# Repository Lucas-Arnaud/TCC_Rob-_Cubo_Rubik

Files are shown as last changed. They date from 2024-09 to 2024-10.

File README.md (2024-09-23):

# Robô Solucionador do Cubo de Rubik com uso de motores de passo e sensores de cor
Trabalho de Conclusão de Curso desenvolvido por Lucas Arnaud de Araújo e orientação do professor Dr. José Rodrigues de Oliveira Neto  submetido ao Departamento de Engenharia Mecânica da Universidade Federal de Pernambuco como requisito parcial para obtenção do título de Bacharel em Engenharia Mecânica.
## Resumo
Este projeto apresenta o desenvolvimento de um robô solucionador do cubo de Rubik, focando em velocidade de resolução e simplicidade da leitura das cores do cubo. Sendo assim, o robô foi projetado com o objetivo de identificar as cores das peças do cubo usando sensores de cor e, com base nesses dados, aplicar um algoritmo eficiente para calcular e executar a sequência de movimentos necessária, com uso de motores de passo, para solucionar o quebra-cabeça. Para esse fim, foram abordados aspectos específicos de projeto mecânico, eletrônica, programação e algoritmos. Com isso, o robô desenvolvido utiliza de seis motores de passo conectados aos eixos centrais do cubo, permitindo a rotação ordenada das faces, para realização da leitura e da resolução do cubo. 

Por outro lado, a leitura das cores é realizada com dois sensores de cor, a partir de um método próprio que realiza a leitura dos 48 quadrados com 60 movimentos das faces. Além disso, se implementou o algoritmo k-ésimo vizinho mais próximo (KNN, do inglês K-nearest neighbors) para classificar em cores os valores capturados pelos sensores e também um código para calcular a precisão das leituras automaticamente a partir de um embaralhamento aleatório empregado no robô. Ademais, utilizou-se uma implementação em código do algoritmo de Kociemba para encontrar a solução do cubo com no máximo 20 movimentos. Além da construção do robô, foram explorados conceitos importantes no uso de microcontroladores e de transferências de dados para integrar sensores e motores com um computador e viabilizar a leitura e a resolução do cubo. 

O projeto foi validado em testes para diferentes padrões do cubo e demonstrou sua capacidade de operar de forma eficaz. Nessas avaliações, o robô alcançou uma mediana de 39 leituras corretas e acertou 1375 das 1776 leituras (77,42\%) de cores. Acerca da velocidade, foi alcançado um tempo mínimo de resolução de 3,3 segundos, um desempenho comparável a projetos de referência na área.
## Imagens

## Importante
Para compreensão detalhada do projeto mecânico, montagem do hardware, códigos implementados, funcionamento do projeto e suas referências consultar o PDF nomeado **TCC_Lucas_Arnaud**.

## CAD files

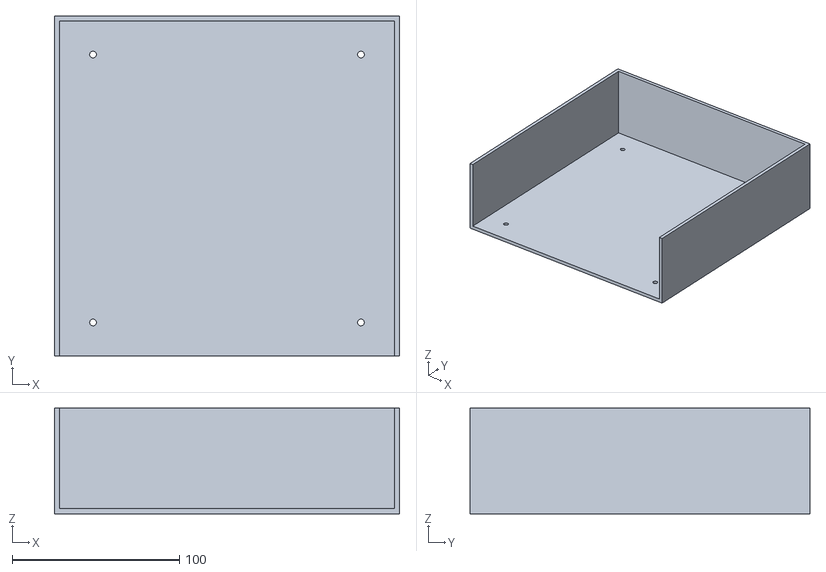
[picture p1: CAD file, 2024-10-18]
PEÇAS_STL/Caixa_Inferior.stl
206.0 x 203.0 x 63.0

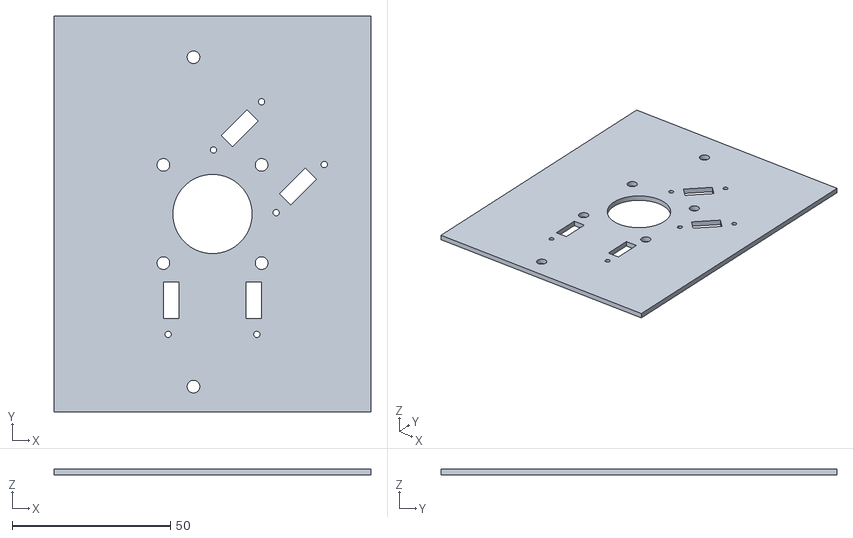
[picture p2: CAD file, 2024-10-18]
PEÇAS_STL/Base_Superior.stl
100.0 x 125.0 x 2.00

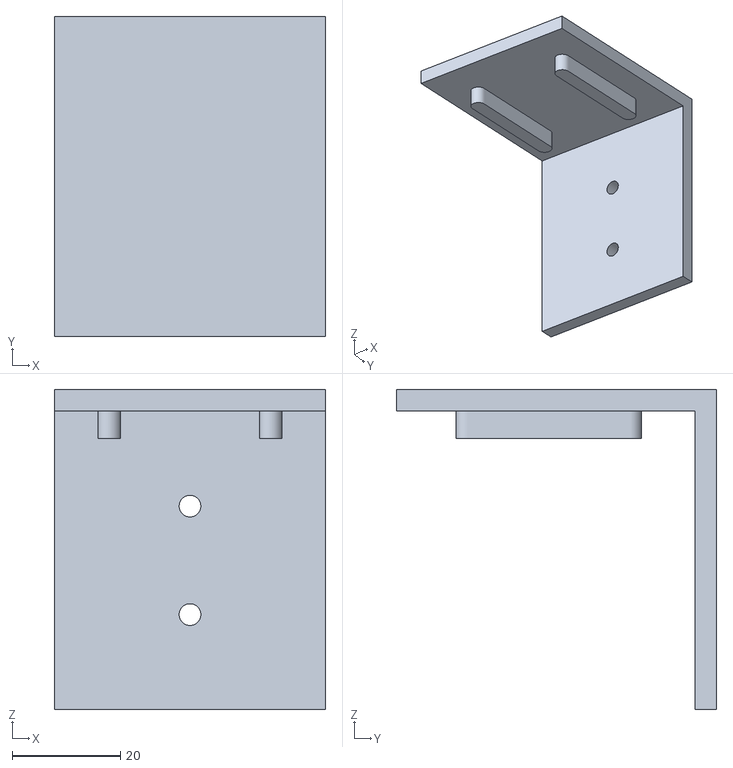
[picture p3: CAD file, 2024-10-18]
PEÇAS_STL/Suporte_Apoio_Reorientado.stl
50.0 x 59.0 x 59.0

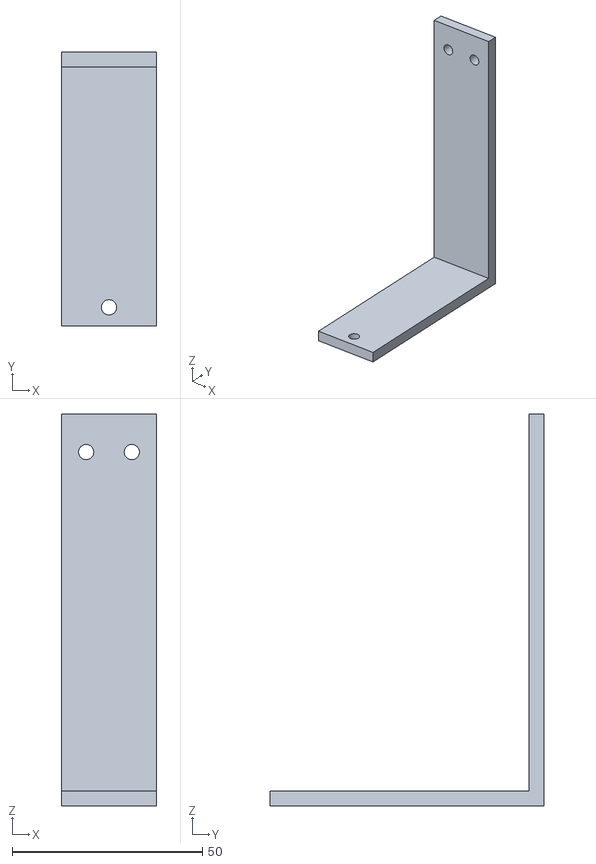
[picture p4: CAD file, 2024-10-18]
PEÇAS_STL/Suporte_em_L.stl
25.0 x 72.0 x 103.0

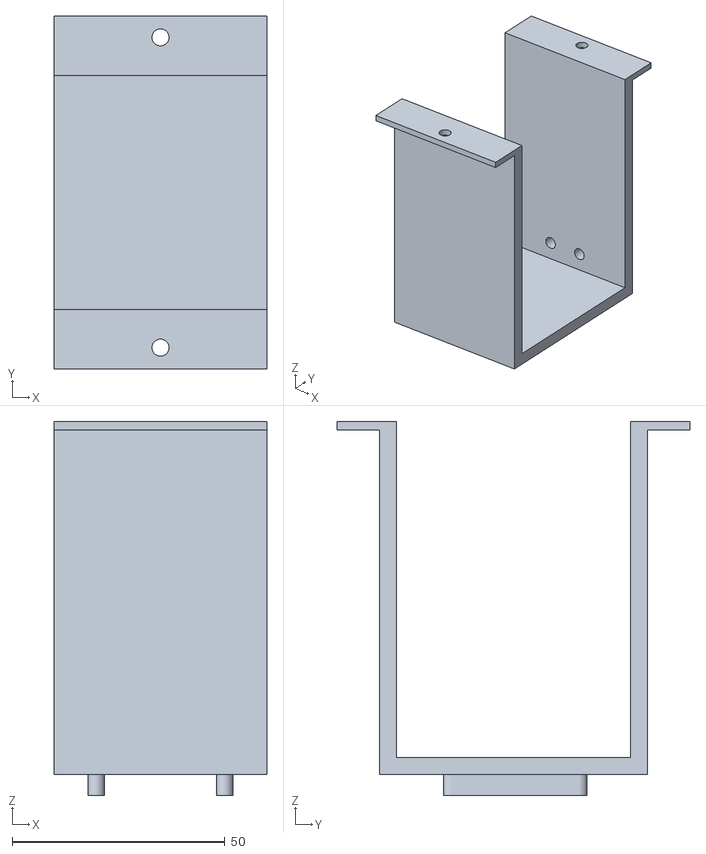
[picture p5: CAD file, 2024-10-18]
PEÇAS_STL/Suportes_Apoio.stl
50.0 x 83.0 x 88.0

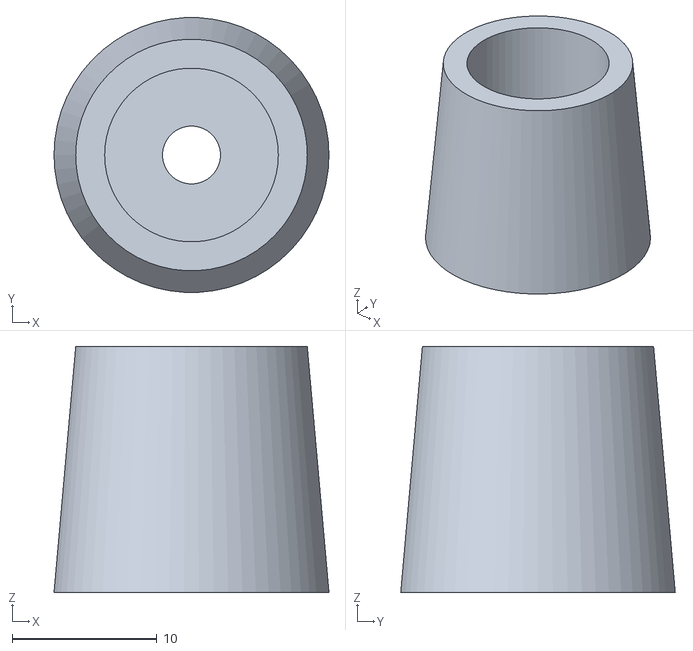
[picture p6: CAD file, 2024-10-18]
PEÇAS_STL/Pezinho (1).stl
19.0 x 19.0 x 17.0

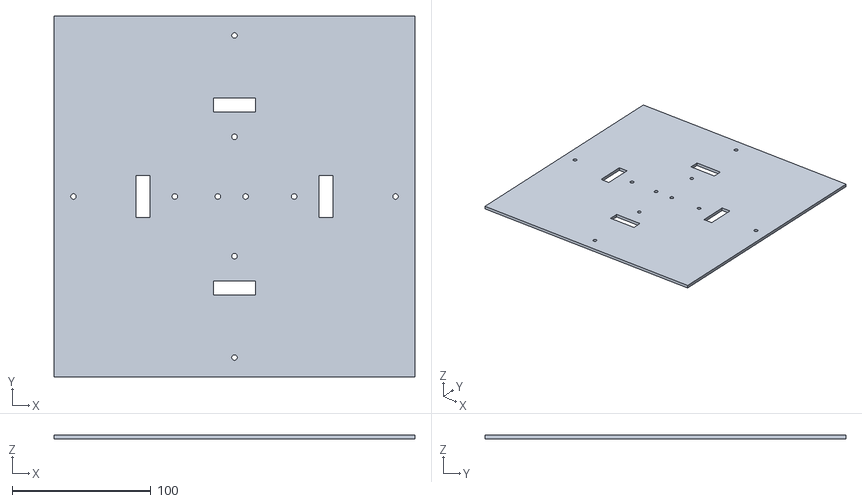
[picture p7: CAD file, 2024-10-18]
PEÇAS_STL/Base_Sustentação_Geral.stl
260.0 x 260.0 x 3.00

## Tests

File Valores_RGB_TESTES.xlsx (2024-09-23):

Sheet: Valores_RGB_Testes
TESTE | SENSOR | PADRÃO | TESTE | R | G | B | COR | SEQUÊNCIA LIDA | SEQUÊNCIA CORRETA
1 | SENSOR 1 | PADRÃO 1 | TESTE 1 | 117 | 115 | 120 | VERMELHO | BDBLBUBUFBUBUFRLRDRLDRFBRFLBRDDRFUBUFDUFUBLLRFUD | FDBLBUBUFBUBUFRLRDRLDRFBLFLBRDDRFUBULDRFUDLLRFUD
2 | SENSOR 1 | PADRÃO 1 | TESTE 1 | 116 | 63 | 53 | VERMELHO | BDBLBUBUFBUBUFRLRDRLDRFBRFLBRDDRFUBUFDUFUBLLRFUD | FDBLBUBUFBUBUFRLRDRLDRFBLFLBRDDRFUBULDRFUDLLRFUD
3 | SENSOR 1 | PADRÃO 1 | TESTE 1 | 152 | 58 | 60 | VERMELHO | BDBLBUBUFBUBUFRLRDRLDRFBRFLBRDDRFUBUFDUFUBLLRFUD | FDBLBUBUFBUBUFRLRDRLDRFBLFLBRDDRFUBULDRFUDLLRFUD
4 | SENSOR 1 | PADRÃO 1 | TESTE 1 | 146 | 58 | 60 | VERMELHO | BDBLBUBUFBUBUFRLRDRLDRFBRFLBRDDRFUBUFDUFUBLLRFUD | FDBLBUBUFBUBUFRLRDRLDRFBLFLBRDDRFUBULDRFUDLLRFUD
5 | SENSOR 1 | PADRÃO 1 | TESTE 1 | 183 | 89 | 60 | LARANJA | BDBLBUBUFBUBUFRLRDRLDRFBRFLBRDDRFUBUFDUFUBLLRFUD | FDBLBUBUFBUBUFRLRDRLDRFBLFLBRDDRFUBULDRFUDLLRFUD
6 | SENSOR 1 | PADRÃO 1 | TESTE 1 | 170 | 84 | 60 | LARANJA | BDBLBUBUFBUBUFRLRDRLDRFBRFLBRDDRFUBUFDUFUBLLRFUD | FDBLBUBUFBUBUFRLRDRLDRFBLFLBRDDRFUBULDRFUDLLRFUD
7 | SENSOR 1 | PADRÃO 1 | TESTE 1 | 152 | 79 | 75 | LARANJA | BDBLBUBUFBUBUFRLRDRLDRFBRFLBRDDRFUBUFDUFUBLLRFUD | FDBLBUBUFBUBUFRLRDRLDRFBLFLBRDDRFUBULDRFUDLLRFUD
8 | SENSOR 1 | PADRÃO 1 | TESTE 1 | 177 | 94 | 60 | LARANJA | BDBLBUBUFBUBUFRLRDRLDRFBRFLBRDDRFUBUFDUFUBLLRFUD | FDBLBUBUFBUBUFRLRDRLDRFBLFLBRDDRFUBULDRFUDLLRFUD
9 | SENSOR 1 | PADRÃO 1 | TESTE 1 | 219 | 209 | 218 | BRANCO | BDBLBUBUFBUBUFRLRDRLDRFBRFLBRDDRFUBUFDUFUBLLRFUD | FDBLBUBUFBUBUFRLRDRLDRFBLFLBRDDRFUBULDRFUDLLRFUD
10 | SENSOR 1 | PADRÃO 1 | TESTE 1 | 225 | 209 | 218 | BRANCO | BDBLBUBUFBUBUFRLRDRLDRFBRFLBRDDRFUBUFDUFUBLLRFUD | FDBLBUBUFBUBUFRLRDRLDRFBLFLBRDDRFUBULDRFUDLLRFUD
11 | SENSOR 1 | PADRÃO 1 | TESTE 1 | 219 | 203 | 218 | BRANCO | BDBLBUBUFBUBUFRLRDRLDRFBRFLBRDDRFUBUFDUFUBLLRFUD | FDBLBUBUFBUBUFRLRDRLDRFBLFLBRDDRFUBULDRFUDLLRFUD
12 | SENSOR 1 | PADRÃO 1 | TESTE 1 | 219 | 203 | 218 | BRANCO | BDBLBUBUFBUBUFRLRDRLDRFBRFLBRDDRFUBUFDUFUBLLRFUD | FDBLBUBUFBUBUFRLRDRLDRFBLFLBRDDRFUBULDRFUDLLRFUD
13 | SENSOR 1 | PADRÃO 1 | TESTE 1 | 170 | 146 | 83 | AMARELO | BDBLBUBUFBUBUFRLRDRLDRFBRFLBRDDRFUBUFDUFUBLLRFUD | FDBLBUBUFBUBUFRLRDRLDRFBLFLBRDDRFUBULDRFUDLLRFUD
14 | SENSOR 1 | PADRÃO 1 | TESTE 1 | 170 | 141 | 83 | AMARELO | BDBLBUBUFBUBUFRLRDRLDRFBRFLBRDDRFUBUFDUFUBLLRFUD | FDBLBUBUFBUBUFRLRDRLDRFBLFLBRDDRFUBULDRFUDLLRFUD
15 | SENSOR 1 | PADRÃO 1 | TESTE 1 | 140 | 136 | 83 | AMARELO | BDBLBUBUFBUBUFRLRDRLDRFBRFLBRDDRFUBUFDUFUBLLRFUD | FDBLBUBUFBUBUFRLRDRLDRFBLFLBRDDRFUBULDRFUDLLRFUD
16 | SENSOR 1 | PADRÃO 1 | TESTE 1 | 152 | 146 | 98 | AMARELO | BDBLBUBUFBUBUFRLRDRLDRFBRFLBRDDRFUBUFDUFUBLLRFUD | FDBLBUBUFBUBUFRLRDRLDRFBLFLBRDDRFUBULDRFUDLLRFUD
17 | SENSOR 1 | PADRÃO 1 | TESTE 1 | 92 | 89 | 60 | VERDE | BDBLBUBUFBUBUFRLRDRLDRFBRFLBRDDRFUBUFDUFUBLLRFUD | FDBLBUBUFBUBUFRLRDRLDRFBLFLBRDDRFUBULDRFUDLLRFUD
18 | SENSOR 1 | PADRÃO 1 | TESTE 1 | 61 | 110 | 75 | VERDE | BDBLBUBUFBUBUFRLRDRLDRFBRFLBRDDRFUBUFDUFUBLLRFUD | FDBLBUBUFBUBUFRLRDRLDRFBLFLBRDDRFUBULDRFUDLLRFUD
19 | SENSOR 1 | PADRÃO 1 | TESTE 1 | 19 | 99 | 90 | VERDE | BDBLBUBUFBUBUFRLRDRLDRFBRFLBRDDRFUBUFDUFUBLLRFUD | FDBLBUBUFBUBUFRLRDRLDRFBLFLBRDDRFUBULDRFUDLLRFUD
20 | SENSOR 1 | PADRÃO 1 | TESTE 1 | 146 | 157 | 188 | VERDE | BDBLBUBUFBUBUFRLRDRLDRFBRFLBRDDRFUBUFDUFUBLLRFUD | FDBLBUBUFBUBUFRLRDRLDRFBLFLBRDDRFUBULDRFUDLLRFUD
21 | SENSOR 1 | PADRÃO 1 | TESTE 1 | 104 | 79 | 98 | AZUL | BDBLBUBUFBUBUFRLRDRLDRFBRFLBRDDRFUBUFDUFUBLLRFUD | FDBLBUBUFBUBUFRLRDRLDRFBLFLBRDDRFUBULDRFUDLLRFUD
22 | SENSOR 1 | PADRÃO 1 | TESTE 1 | 37 | 63 | 113 | AZUL | BDBLBUBUFBUBUFRLRDRLDRFBRFLBRDDRFUBUFDUFUBLLRFUD | FDBLBUBUFBUBUFRLRDRLDRFBLFLBRDDRFUBULDRFUDLLRFUD
23 | SENSOR 1 | PADRÃO 1 | TESTE 1 | 55 | 73 | 98 | AZUL | BDBLBUBUFBUBUFRLRDRLDRFBRFLBRDDRFUBUFDUFUBLLRFUD | FDBLBUBUFBUBUFRLRDRLDRFBLFLBRDDRFUBULDRFUDLLRFUD
24 | SENSOR 1 | PADRÃO 1 | TESTE 1 | 146 | 157 | 188 | AZUL | BDBLBUBUFBUBUFRLRDRLDRFBRFLBRDDRFUBUFDUFUBLLRFUD | FDBLBUBUFBUBUFRLRDRLDRFBLFLBRDDRFUBULDRFUDLLRFUD
25 | SENSOR 2 | PADRÃO 1 | TESTE 1 | 158 | 153 | 55 | VERMELHO | BDBLBUBUFBUBUFRLRDRLDRFBRFLBRDDRFUBUFDUFUBLLRFUD | FDBLBUBUFBUBUFRLRDRLDRFBLFLBRDDRFUBULDRFUDLLRFUD
26 | SENSOR 2 | PADRÃO 1 | TESTE 1 | 163 | 53 | 51 | VERMELHO | BDBLBUBUFBUBUFRLRDRLDRFBRFLBRDDRFUBUFDUFUBLLRFUD | FDBLBUBUFBUBUFRLRDRLDRFBLFLBRDDRFUBULDRFUDLLRFUD
27 | SENSOR 2 | PADRÃO 1 | TESTE 1 | 158 | 47 | 38 | VERMELHO | BDBLBUBUFBUBUFRLRDRLDRFBRFLBRDDRFUBUFDUFUBLLRFUD | FDBLBUBUFBUBUFRLRDRLDRFBLFLBRDDRFUBULDRFUDLLRFUD
28 | SENSOR 2 | PADRÃO 1 | TESTE 1 | 163 | 47 | 42 | VERMELHO | BDBLBUBUFBUBUFRLRDRLDRFBRFLBRDDRFUBUFDUFUBLLRFUD | FDBLBUBUFBUBUFRLRDRLDRFBLFLBRDDRFUBULDRFUDLLRFUD
29 | SENSOR 2 | PADRÃO 1 | TESTE 1 | 190 | 103 | 97 | LARANJA | BDBLBUBUFBUBUFRLRDRLDRFBRFLBRDDRFUBUFDUFUBLLRFUD | FDBLBUBUFBUBUFRLRDRLDRFBLFLBRDDRFUBULDRFUDLLRFUD
30 | SENSOR 2 | PADRÃO 1 | TESTE 1 | 201 | 106 | 76 | LARANJA | BDBLBUBUFBUBUFRLRDRLDRFBRFLBRDDRFUBUFDUFUBLLRFUD | FDBLBUBUFBUBUFRLRDRLDRFBLFLBRDDRFUBULDRFUDLLRFUD
31 | SENSOR 2 | PADRÃO 1 | TESTE 1 | 193 | 106 | 72 | LARANJA | BDBLBUBUFBUBUFRLRDRLDRFBRFLBRDDRFUBUFDUFUBLLRFUD | FDBLBUBUFBUBUFRLRDRLDRFBLFLBRDDRFUBULDRFUDLLRFUD
32 | SENSOR 2 | PADRÃO 1 | TESTE 1 | 190 | 100 | 72 | LARANJA | BDBLBUBUFBUBUFRLRDRLDRFBRFLBRDDRFUBUFDUFUBLLRFUD | FDBLBUBUFBUBUFRLRDRLDRFBLFLBRDDRFUBULDRFUDLLRFUD
33 | SENSOR 2 | PADRÃO 1 | TESTE 1 | 231 | 246 | 230 | BRANCO | BDBLBUBUFBUBUFRLRDRLDRFBRFLBRDDRFUBUFDUFUBLLRFUD | FDBLBUBUFBUBUFRLRDRLDRFBLFLBRDDRFUBULDRFUDLLRFUD
34 | SENSOR 2 | PADRÃO 1 | TESTE 1 | 247 | 242 | 230 | BRANCO | BDBLBUBUFBUBUFRLRDRLDRFBRFLBRDDRFUBUFDUFUBLLRFUD | FDBLBUBUFBUBUFRLRDRLDRFBLFLBRDDRFUBULDRFUDLLRFUD
35 | SENSOR 2 | PADRÃO 1 | TESTE 1 | 237 | 242 | 226 | BRANCO | BDBLBUBUFBUBUFRLRDRLDRFBRFLBRDDRFUBUFDUFUBLLRFUD | FDBLBUBUFBUBUFRLRDRLDRFBLFLBRDDRFUBULDRFUDLLRFUD
36 | SENSOR 2 | PADRÃO 1 | TESTE 1 | 231 | 239 | 226 | BRANCO | BDBLBUBUFBUBUFRLRDRLDRFBRFLBRDDRFUBUFDUFUBLLRFUD | FDBLBUBUFBUBUFRLRDRLDRFBLFLBRDDRFUBULDRFUDLLRFUD
37 | SENSOR 2 | PADRÃO 1 | TESTE 1 | 215 | 183 | 101 | AMARELO | BDBLBUBUFBUBUFRLRDRLDRFBRFLBRDDRFUBUFDUFUBLLRFUD | FDBLBUBUFBUBUFRLRDRLDRFBLFLBRDDRFUBULDRFUDLLRFUD
38 | SENSOR 2 | PADRÃO 1 | TESTE 1 | 196 | 179 | 97 | AMARELO | BDBLBUBUFBUBUFRLRDRLDRFBRFLBRDDRFUBUFDUFUBLLRFUD | FDBLBUBUFBUBUFRLRDRLDRFBLFLBRDDRFUBULDRFUDLLRFUD
39 | SENSOR 2 | PADRÃO 1 | TESTE 1 | 152 | 110 | 159 | AMARELO | BDBLBUBUFBUBUFRLRDRLDRFBRFLBRDDRFUBUFDUFUBLLRFUD | FDBLBUBUFBUBUFRLRDRLDRFBLFLBRDDRFUBULDRFUDLLRFUD
40 | SENSOR 2 | PADRÃO 1 | TESTE 1 | 85 | 153 | 134 | AMARELO | BDBLBUBUFBUBUFRLRDRLDRFBRFLBRDDRFUBUFDUFUBLLRFUD | FDBLBUBUFBUBUFRLRDRLDRFBLFLBRDDRFUBULDRFUDLLRFUD
41 | SENSOR 2 | PADRÃO 1 | TESTE 1 | 66 | 116 | 84 | VERDE | BDBLBUBUFBUBUFRLRDRLDRFBRFLBRDDRFUBUFDUFUBLLRFUD | FDBLBUBUFBUBUFRLRDRLDRFBLFLBRDDRFUBULDRFUDLLRFUD
42 | SENSOR 2 | PADRÃO 1 | TESTE 1 | 60 | 116 | 80 | VERDE | BDBLBUBUFBUBUFRLRDRLDRFBRFLBRDDRFUBUFDUFUBLLRFUD | FDBLBUBUFBUBUFRLRDRLDRFBLFLBRDDRFUBULDRFUDLLRFUD
43 | SENSOR 2 | PADRÃO 1 | TESTE 1 | 55 | 110 | 67 | VERDE | BDBLBUBUFBUBUFRLRDRLDRFBRFLBRDDRFUBUFDUFUBLLRFUD | FDBLBUBUFBUBUFRLRDRLDRFBLFLBRDDRFUBULDRFUDLLRFUD
44 | SENSOR 2 | PADRÃO 1 | TESTE 1 | 66 | 123 | 84 | VERDE | BDBLBUBUFBUBUFRLRDRLDRFBRFLBRDDRFUBUFDUFUBLLRFUD | FDBLBUBUFBUBUFRLRDRLDRFBLFLBRDDRFUBULDRFUDLLRFUD
45 | SENSOR 2 | PADRÃO 1 | TESTE 1 | 60 | 87 | 126 | AZUL | BDBLBUBUFBUBUFRLRDRLDRFBRFLBRDDRFUBUFDUFUBLLRFUD | FDBLBUBUFBUBUFRLRDRLDRFBLFLBRDDRFUBULDRFUDLLRFUD
46 | SENSOR 2 | PADRÃO 1 | TESTE 1 | 47 | 70 | 143 | AZUL | BDBLBUBUFBUBUFRLRDRLDRFBRFLBRDDRFUBUFDUFUBLLRFUD | FDBLBUBUFBUBUFRLRDRLDRFBLFLBRDDRFUBULDRFUDLLRFUD
47 | SENSOR 2 | PADRÃO 1 | TESTE 1 | 55 | 80 | 122 | AZUL | BDBLBUBUFBUBUFRLRDRLDRFBRFLBRDDRFUBUFDUFUBLLRFUD | FDBLBUBUFBUBUFRLRDRLDRFBLFLBRDDRFUBULDRFUDLLRFUD
48 | SENSOR 2 | PADRÃO 1 | TESTE 1 | 60 | 83 | 122 | AZUL | BDBLBUBUFBUBUFRLRDRLDRFBRFLBRDDRFUBUFDUFUBLLRFUD | FDBLBUBUFBUBUFRLRDRLDRFBLFLBRDDRFUBULDRFUDLLRFUD
49 | SENSOR 1 | PADRÃO 1 | TESTE 2 | 170 | 110 | 113 | VERMELHO | FDBLBUBUFBUBUFRLRDRLDRLBLFLBRFDRFUBUFDUFUBLLRFUR | FDBLBUBUFBUBUFRLRDRLDRFBLFLBRDDRFUBULDRFUDLLRFUD
50 | SENSOR 1 | PADRÃO 1 | TESTE 2 | 104 | 89 | 45 | VERMELHO | FDBLBUBUFBUBUFRLRDRLDRLBLFLBRFDRFUBUFDUFUBLLRFUR | FDBLBUBUFBUBUFRLRDRLDRFBLFLBRDDRFUBULDRFUDLLRFUD
51 | SENSOR 1 | PADRÃO 1 | TESTE 2 | 146 | 53 | 53 | VERMELHO | FDBLBUBUFBUBUFRLRDRLDRLBLFLBRFDRFUBUFDUFUBLLRFUR | FDBLBUBUFBUBUFRLRDRLDRFBLFLBRDDRFUBULDRFUDLLRFUD
52 | SENSOR 1 | PADRÃO 1 | TESTE 2 | 152 | 58 | 60 | VERMELHO | FDBLBUBUFBUBUFRLRDRLDRLBLFLBRFDRFUBUFDUFUBLLRFUR | FDBLBUBUFBUBUFRLRDRLDRFBLFLBRDDRFUBULDRFUDLLRFUD
53 | SENSOR 1 | PADRÃO 1 | TESTE 2 | 183 | 84 | 45 | LARANJA | FDBLBUBUFBUBUFRLRDRLDRLBLFLBRFDRFUBUFDUFUBLLRFUR | FDBLBUBUFBUBUFRLRDRLDRFBLFLBRDDRFUBULDRFUDLLRFUD
54 | SENSOR 1 | PADRÃO 1 | TESTE 2 | 164 | 79 | 53 | LARANJA | FDBLBUBUFBUBUFRLRDRLDRLBLFLBRFDRFUBUFDUFUBLLRFUR | FDBLBUBUFBUBUFRLRDRLDRFBLFLBRDDRFUBULDRFUDLLRFUD
55 | SENSOR 1 | PADRÃO 1 | TESTE 2 | 152 | 79 | 75 | LARANJA | FDBLBUBUFBUBUFRLRDRLDRLBLFLBRFDRFUBUFDUFUBLLRFUR | FDBLBUBUFBUBUFRLRDRLDRFBLFLBRDDRFUBULDRFUDLLRFUD
56 | SENSOR 1 | PADRÃO 1 | TESTE 2 | 183 | 94 | 60 | LARANJA | FDBLBUBUFBUBUFRLRDRLDRLBLFLBRFDRFUBUFDUFUBLLRFUR | FDBLBUBUFBUBUFRLRDRLDRFBLFLBRDDRFUBULDRFUDLLRFUD
57 | SENSOR 1 | PADRÃO 1 | TESTE 2 | 219 | 203 | 210 | BRANCO | FDBLBUBUFBUBUFRLRDRLDRLBLFLBRFDRFUBUFDUFUBLLRFUR | FDBLBUBUFBUBUFRLRDRLDRFBLFLBRDDRFUBULDRFUDLLRFUD
58 | SENSOR 1 | PADRÃO 1 | TESTE 2 | 219 | 203 | 210 | BRANCO | FDBLBUBUFBUBUFRLRDRLDRLBLFLBRFDRFUBUFDUFUBLLRFUR | FDBLBUBUFBUBUFRLRDRLDRFBLFLBRDDRFUBULDRFUDLLRFUD
59 | SENSOR 1 | PADRÃO 1 | TESTE 2 | 213 | 193 | 203 | BRANCO | FDBLBUBUFBUBUFRLRDRLDRLBLFLBRFDRFUBUFDUFUBLLRFUR | FDBLBUBUFBUBUFRLRDRLDRFBLFLBRDDRFUBULDRFUDLLRFUD
60 | SENSOR 1 | PADRÃO 1 | TESTE 2 | 213 | 198 | 210 | BRANCO | FDBLBUBUFBUBUFRLRDRLDRLBLFLBRFDRFUBUFDUFUBLLRFUR | FDBLBUBUFBUBUFRLRDRLDRFBLFLBRDDRFUBULDRFUDLLRFUD
61 | SENSOR 1 | PADRÃO 1 | TESTE 2 | 164 | 136 | 68 | AMARELO | FDBLBUBUFBUBUFRLRDRLDRLBLFLBRFDRFUBUFDUFUBLLRFUR | FDBLBUBUFBUBUFRLRDRLDRFBLFLBRDDRFUBULDRFUDLLRFUD
62 | SENSOR 1 | PADRÃO 1 | TESTE 2 | 164 | 136 | 75 | AMARELO | FDBLBUBUFBUBUFRLRDRLDRLBLFLBRFDRFUBUFDUFUBLLRFUR | FDBLBUBUFBUBUFRLRDRLDRFBLFLBRDDRFUBULDRFUDLLRFUD
63 | SENSOR 1 | PADRÃO 1 | TESTE 2 | 140 | 136 | 128 | AMARELO | FDBLBUBUFBUBUFRLRDRLDRLBLFLBRFDRFUBUFDUFUBLLRFUR | FDBLBUBUFBUBUFRLRDRLDRFBLFLBRDDRFUBULDRFUDLLRFUD
64 | SENSOR 1 | PADRÃO 1 | TESTE 2 | 152 | 141 | 90 | AMARELO | FDBLBUBUFBUBUFRLRDRLDRLBLFLBRFDRFUBUFDUFUBLLRFUR | FDBLBUBUFBUBUFRLRDRLDRFBLFLBRDDRFUBULDRFUDLLRFUD
65 | SENSOR 1 | PADRÃO 1 | TESTE 2 | 79 | 79 | 45 | VERDE | FDBLBUBUFBUBUFRLRDRLDRLBLFLBRFDRFUBUFDUFUBLLRFUR | FDBLBUBUFBUBUFRLRDRLDRFBLFLBRDDRFUBULDRFUDLLRFUD
66 | SENSOR 1 | PADRÃO 1 | TESTE 2 | 49 | 99 | 68 | VERDE | FDBLBUBUFBUBUFRLRDRLDRLBLFLBRFDRFUBUFDUFUBLLRFUR | FDBLBUBUFBUBUFRLRDRLDRFBLFLBRDDRFUBULDRFUDLLRFUD
67 | SENSOR 1 | PADRÃO 1 | TESTE 2 | 19 | 94 | 83 | VERDE | FDBLBUBUFBUBUFRLRDRLDRLBLFLBRFDRFUBUFDUFUBLLRFUR | FDBLBUBUFBUBUFRLRDRLDRFBLFLBRDDRFUBULDRFUDLLRFUD
68 | SENSOR 1 | PADRÃO 1 | TESTE 2 | 146 | 162 | 165 | VERDE | FDBLBUBUFBUBUFRLRDRLDRLBLFLBRFDRFUBUFDUFUBLLRFUR | FDBLBUBUFBUBUFRLRDRLDRFBLFLBRDDRFUBULDRFUDLLRFUD
69 | SENSOR 1 | PADRÃO 1 | TESTE 2 | 104 | 73 | 98 | AZUL | FDBLBUBUFBUBUFRLRDRLDRLBLFLBRFDRFUBUFDUFUBLLRFUR | FDBLBUBUFBUBUFRLRDRLDRFBLFLBRDDRFUBULDRFUDLLRFUD
70 | SENSOR 1 | PADRÃO 1 | TESTE 2 | 25 | 53 | 98 | AZUL | FDBLBUBUFBUBUFRLRDRLDRLBLFLBRFDRFUBUFDUFUBLLRFUR | FDBLBUBUFBUBUFRLRDRLDRFBLFLBRDDRFUBULDRFUDLLRFUD
71 | SENSOR 1 | PADRÃO 1 | TESTE 2 | 49 | 73 | 90 | AZUL | FDBLBUBUFBUBUFRLRDRLDRLBLFLBRFDRFUBUFDUFUBLLRFUR | FDBLBUBUFBUBUFRLRDRLDRFBLFLBRDDRFUBULDRFUDLLRFUD
72 | SENSOR 1 | PADRÃO 1 | TESTE 2 | 152 | 157 | 195 | AZUL | FDBLBUBUFBUBUFRLRDRLDRLBLFLBRFDRFUBUFDUFUBLLRFUR | FDBLBUBUFBUBUFRLRDRLDRFBLFLBRDDRFUBULDRFUDLLRFUD
73 | SENSOR 2 | PADRÃO 1 | TESTE 2 | 152 | 34 | 34 | VERMELHO | FDBLBUBUFBUBUFRLRDRLDRLBLFLBRFDRFUBUFDUFUBLLRFUR | FDBLBUBUFBUBUFRLRDRLDRFBLFLBRDDRFUBULDRFUDLLRFUD
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

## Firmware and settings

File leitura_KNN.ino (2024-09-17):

// Autor: Lucas Arnaud de Araújo
// Trabalho de Conclusão de Curso em Engenharia Mecânica
// Universidade Federal de Pernambuco
// Projeto: ROBÔ SOLUCIONADOR DO CUBO DE RUBIK COM USO DE MOTORES DE PASSO E SENSORES DE COR
// Nome do arquivo: leitura_KNN (instalado no Arduino UNO)
// Data de atualização: 17/09/2024

// Este código se divide em 3 partes:
// Parte 1: declarações de funções e variáveis, definição dos pinos dos dois sensores e inicialização da serial;
// Parte 2: loop para realizar leituras ou imprimir sequência lida;
// Parte 3: funções de cada um dos sensores para classificar valores RGB em cores pelo algoritmo KNN.

// Para mais detalhes acesse o arquivo PDF denominado [TCC_Lucas_Arnaud] disponibilizado nesta pasta do github.

//////////////////////////////////// PARTE 1 ////////////////////////////////////

/////////////// DECLARAÇÃO DAS VARIÁVEIS E FUNÇÕES ////////////////

int red[2]; //Declaração da variável que representará a cor vermelha
int green[2]; //Declaração da variável que representará a cor verde
int blue[2]; // Declaração da variável que representará a cor azul
bool fazer_Leitura = false;
String sequencia_cores = ""; // String para armazenar a sequência de cores lidas
int sensorAtual = -1; // Variável para armazenar qual sensor usar

void classificar_cor_1(int red, int green, int blue); // Inicialização da função de classificação do SENSOR 1
void classificar_cor_2(int red, int green, int blue); // Inicialização da função de classificação do SENSOR 2

/////////////// DEFINIÇÃO DOS PINOS E INICIALIZAÇÃO DA SERIAL ////////////////

#define PinS2_1  4 //Definição do Pino S2_1 na entrada digital 3
#define PinS3_1 3 //Definição do Pino S3_1 na entrada digital 4
#define PinOUT_1 5 //Definição do Pino OUT_1 na entrada digital 5

#define PinS2_2  9 //Definição do Pino S2_2 na entrada digital 8
#define PinS3_2 8 //Definição do Pino S3_2 na entrada digital 9
#define PinOUT_2 10 //Definição do Pino OUT_2 na entrada digital 10

void setup() {
  pinMode(PinOUT_1, INPUT); //Definição do PinOUT como sendo um pino de entrada
  pinMode(PinS2_1, OUTPUT); //Definição do Pino S2 como sendo um pino de saída
  pinMode(PinS3_1, OUTPUT); //Definição do Pino S3 como sendo um pino de saída
  
  pinMode(PinOUT_2, INPUT); //Definição do PinOUT como sendo um pino de entrada
  pinMode(PinS2_2, OUTPUT); //Definição do Pino S2 como sendo um pino de saída
  pinMode(PinS3_2, OUTPUT); //Definição do Pino S3 como sendo um pino de saída

  Serial.begin(9600); //Inicia a Serial com velocidade de 9600 bps
}

//////////////////////////////////// PARTE 2 ////////////////////////////////////

/////////////// LOOP PARA REALIZAR LEITURAS OU IMPRIMIR SEQUÊNCIA LIDA ////////////////

void loop() {
  if (Serial.available() > 0) { // Verifica se há dados disponíveis na porta serial
    String input = Serial.readStringUntil('\n'); // Lê a linha recebida

    if (input == "L1") { // Se o caractere recebido for 'L1'
      sensorAtual = 1; // Define sensorAtual como 1
      fazer_Leitura = true; // Define fazer_Leitura como verdadeiro
    } else if (input == "L2") { // Se o caractere recebido for 'L2'
      sensorAtual = 2; // Define sensorAtual como 2
      fazer_Leitura = true; // Define fazer_Leitura como verdadeiro
    } else if (input == "P") { // Se o caractere recebido for 'P'
      Serial.println(sequencia_cores); // Imprime a sequência de cores armazenada
    }
  }

  if (fazer_Leitura) { // Se fazer_Leitura for verdadeiro
    if (sensorAtual == 1) {
      // Leitura das cores do sensor 1
      digitalWrite(PinS2_1, LOW); // Aciona um valor LOW ao Pino S2
      digitalWrite(PinS3_1, LOW); // Aciona um valor LOW ao Pino S3
      red[0] = pulseIn(PinOUT_1, LOW); // define red como sendo responsável por ler a informação de pulso LOW do pino out
      red[0] = map (red[0], 13, 55, 255, 0); //mapeia o pulso lido para um valor entre 0 a 255
      delay(15); // delay de 15 milissegundos até o próximo comando
      digitalWrite(PinS2_1, HIGH); // Aciona um valor HIGH ao Pino S2
      digitalWrite(PinS3_1, HIGH); // Aciona um valor HIGH ao Pino S3
      green[0] = pulseIn(PinOUT_1, LOW); // define green como sendo responsável por ler a informação de pulso LOW do pino out
      green[0] = map (green[0], 11, 60, 255, 0); //mapeia o pulso lido para um valor entre 0 a 255
      delay(15); // delay de 15 milissegundos até o próximo comando
      digitalWrite(PinS2_1, LOW); // Aciona um valor LOW ao Pino S2
      digitalWrite(PinS3_1, HIGH); // Aciona um valor HIGH ao Pino S3
      blue[0] = pulseIn(PinOUT_1, LOW); // define blue como sendo responsável por ler a informação de pulso LOW do pino out
      blue[0] = map (blue[0], 13, 47, 255, 0); //mapeia o pulso lido para um valor entre 0 a 255
      delay(15); // delay de 15 milissegundos até o próximo comando

      // Imprimindo valores RGB do SENSOR 1
      Serial.print("Sensor 1: ");
      Serial.print(red[0]);
      Serial.print("\t| ");
      Serial.print(green[0]);
      Serial.print("\t| ");
      Serial.print(blue[0]);
      Serial.print("\t| ");
      // Aplica os valores na função de classificação do SENSOR 1 para definir a cor lida
      classificar_cor_1(red[0], green[0], blue[0]);
      
    } else if (sensorAtual == 2) {
      // Leitura das cores do sensor 2
      digitalWrite(PinS2_2, LOW); // Aciona um valor LOW ao Pino S2
      digitalWrite(PinS3_2, LOW); // Aciona um valor LOW ao Pino S3
      red[1] = pulseIn(PinOUT_2, LOW); // define red como sendo responsável por ler a informação de pulso LOW do pino out
      red[1] = map (red[1], 17, 111, 255, 0); //mapeia o pulso lido para um valor entre 0 a 255
      delay(15); // delay de 15 milissegundos até o próximo comando
      digitalWrite(PinS2_2, HIGH); // Aciona um valor HIGH ao Pino S2
      digitalWrite(PinS3_2, HIGH); // Aciona um valor HIGH ao Pino S3
      green[1] = pulseIn(PinOUT_2, LOW); // define green como sendo responsável por ler a informação de pulso LOW do pino out
      green[1] = map (green[1], 19, 96, 255, 0); //mapeia o pulso lido para um valor entre 0 a 255
      delay(15); // delay de 15 milissegundos até o próximo comando
      digitalWrite(PinS2_2, LOW); // Aciona um valor LOW ao Pino S2
      digitalWrite(PinS3_2, HIGH); // Aciona um valor HIGH ao Pino S3
      blue[1] = pulseIn(PinOUT_2, LOW); // define blue como sendo responsável por ler a informação de pulso LOW do pino out
      blue[1] = map (blue[1], 14, 75, 255, 0); //mapeia o pulso lido para um valor entre 0 a 255
      delay(15); // delay de 15 milissegundos até o próximo comando

      // Imprimindo valores RGB do SENSOR 2
      Serial.print("Sensor 2: ");
      Serial.print(red[1]);
      Serial.print("\t| ");
      Serial.print(green[1]);
      Serial.print("\t| ");
      Serial.print(blue[1]);
      Serial.print("\t| ");
      // Aplica os valores na função de classificação do SENSOR 2 para definir a cor lida
      classificar_cor_2(red[1], green[1], blue[1]);
    }
    fazer_Leitura = false; // atribue valor false a variável fazer_Leitura para que outra solicitação de leitura possa ser feita
  }
}

//////////////////////////////////// PARTE 3 ////////////////////////////////////

/////////////// FUNÇÃO PARA CLASSIFICAR OS VALORES RGB DO SENSOR 1 EM COR PELO ALGORITMO KNN ////////////////

void classificar_cor_1(int red, int green, int blue) {

 // 10 amostras (red, green, blue) de cada cor ("U - Branco", "D - Amarelo", "F - Vermelho", "B - Laranja",  "L - Verde", "R - Azul")
  int amostras[60][3] = {
    {219, 203, 210}, {213, 203, 218}, {225, 203, 218}, {219, 203, 218}, {219, 229, 218}, {213, 208, 218}, {213, 193, 203}, 
    {206, 187, 195}, {206, 193, 203}, {200, 187, 195}, //BRANCO
    {158, 114, 38}, {158, 146, 38}, {134, 104, 45}, {152, 114, 53}, {152, 125, 53}, {140, 130, 68}, {188, 120, 60},
    {164, 125, 60}, {176, 135, 75}, {170, 135, 75}, // AMARELO
    {170, 99, 105}, {176, 135, 150}, {152, 99, 98}, {140, 104, 38}, {109, 26, 45}, {164, 104, 90}, {128, 62, 45}, 
    {146, 52, 60}, {134, 62, 45}, {158, 104, 90}, //VERMELHO
    {170, 78, 45}, {176, 114, 68}, {170, 109, 90}, {164, 88, 75}, {188, 141, 135}, {164, 83, 68}, {152, 83, 113},
    {188, 130, 120}, {146, 78, 83}, {158, 83, 83}, //LARANJA
    {61, 104, 68}, {79, 99, 68}, {73, 99, 60}, {73, 114, 90}, {115, 135, 128}, {55, 78, 68}, {30, 78, 68}, 
    {97, 99, 75}, {85, 109, 98}, {109, 104, 60}, //VERDE
    {55, 99, 105}, {55, 52, 83}, {43, 73, 90}, {61, 62, 98}, {67, 83, 98}, {67, 52, 90}, {67, 83, 120}, {103, 94, 113}, 
    {79, 73, 105}, {91, 73, 113} // AZUL
};
  // Nome das cores
  String cores[6] = {"U - Branco", "D - Amarelo", "F - Vermelho", "B - Laranja",  "L - Verde", "R - Azul"};

  // Armazena as distâncias e os índices de cores correspondentes
  float distancias[60];
  int indices_cor[60];

  // Calcula a distância euclidiana para cada amostra
  for (int i = 0; i < 60; i++) {
    int amostraRed = amostras[i][0];
    int amostraGreen = amostras[i][1];
    int amostraBlue = amostras[i][2];

    distancias[i] = sqrt(
      pow((red - amostraRed), 2) +
      pow((green - amostraGreen), 2) +
      pow((blue - amostraBlue), 2)
    );

    // Classificar as amostras em cores (divisão por 6 blocos de 10)
    if (i < 10) {
      indices_cor[i] = 0; // Branco
    } else if (i < 20) {
      indices_cor[i] = 1; // Amarelo
    } else if (i < 30) {
      indices_cor[i] = 2; // Vermelho
    } else if (i < 40) {
      indices_cor[i] = 3; // Laranja
    } else if (i < 50) {
      indices_cor[i] = 4; // Verde
    } else {
      indices_cor[i] = 5; // Azul
    }
  }

  // Ordena as distâncias (com bubble sort)
  for (int i = 0; i < 59; i++) {
    for (int j = 0; j < 59 - i; j++) {
      if (distancias[j] > distancias[j + 1]) {
        // Troca de distâncias
        float tempDist = distancias[j];
        distancias[j] = distancias[j + 1];
        distancias[j + 1] = tempDist;

        // Troca de índices de cor correspondente
        int tempIndex = indices_cor[j];
        indices_cor[j] = indices_cor[j + 1];
        indices_cor[j + 1] = tempIndex;
      }
    }
  }

  // Se faz a votação com os 3 vizinhos mais próximos (K=3)
  int votos[6] = {0, 0, 0, 0, 0, 0};  // 6 posições, uma para cada cor

  for (int i = 0; i < 3; i++) {
    votos[indices_cor[i]]++;  // Adiciona um voto para a cor correspondente
  }

  // Encontra a cor com o maior número de votos
  int maiorVoto = 0;
  int indiceCor = -1;
  for (int i = 0; i < 6; i++) {
    if (votos[i] > maiorVoto) {
      maiorVoto = votos[i];
      indiceCor = i;
    }
  }

  // Exibe a cor identificada
  if (indiceCor != -1) {
    Serial.println(cores[indiceCor]); // Imprime na serial a cor identificada
    sequencia_cores += cores[indiceCor].charAt(0);  // Armazena a primeira letra da cor da sequência de cores
  } else { // Se a cor for desconhecida, imprime mensagem na serial e adiciona 'X' na sequencia de cores lidas
    Serial.println("Desconhecida");
    sequencia_cores += 'X';
  }
}

/////////////// FUNÇÃO PARA CLASSIFICAR OS VALORES RGB DO SENSOR 2 EM COR PELO ALGORITMO KNN ////////////////

void classificar_cor_2(int red, int green, int blue) {

   // 10 amostras (red, green, blue) de cada cor ("U - Branco", "D - Amarelo", "F - Vermelho", "B - Laranja",  "L - Verde", "R - Azul")
  int amostras[30][3] = {
    {228, 238, 230}, {231, 238, 230}, {231, 235, 230}, {231, 238, 234}, {225, 232, 230},// BRANCO
    {184, 162, 79}, {190, 169, 92}, {187, 166, 88}, {184, 162, 84}, {193, 176, 96}, // AMARELO
    {152, 33, 63}, {155, 30, 42}, {152, 43, 54}, {155, 36, 42}, {152, 33, 46}, // VERMELHO
    {184, 93, 54}, {187, 93, 84}, {182, 106, 63}, {171, 86, 75}, {187, 96, 59},  // LARANJA
    {35, 93, 50}, {33, 89, 54}, {30, 89, 50}, {27, 86, 46}, {33, 89, 46},  // VERDE
    {22, 46, 92}, {22, 40, 88}, {19, 46, 121}, {27, 50, 100}, {35, 56, 100},  // AZUL
};

  // Nome das cores
  String cores[6] = {"U - Branco", "D - Amarelo", "F - Vermelho", "B - Laranja", "L - Verde", "R - Azul"};

  // Armazena as distâncias e os índice de cores correspondentes
  float distancias[30];
  int indices_cor[30];

  // Calcula a distância euclidiana para cada amostra
  for (int i = 0; i < 30; i++) {
    int amostraRed = amostras[i][0];
    int amostraGreen = amostras[i][1];
    int amostraBlue = amostras[i][2];

    distancias[i] = sqrt(
      pow((red - amostraRed), 2) +
      pow((green - amostraGreen), 2) +
      pow((blue - amostraBlue), 2)
    );

    // Classifica as amostras em cores (divisão por 6 blocos de 5)
    if (i < 5) {
      indices_cor[i] = 0; // Branco
    } else if (i < 10) {
      indices_cor[i] = 1; // Amarelo
    } else if (i < 15) {
      indices_cor[i] = 2; // Vermelho
    } else if (i < 20) {
      indices_cor[i] = 3; // Laranja
    } else if (i < 25) {
      indices_cor[i] = 4; // Verde
    } else {
      indices_cor[i] = 5; // Azul
    }
  }

  // Ordenar as distâncias (com bubble sort)
  for (int i = 0; i < 29; i++) {
    for (int j = 0; j < 29 - i; j++) {
      if (distancias[j] > distancias[j + 1]) {
        // Troca de distâncias
        float tempDist = distancias[j];
        distancias[j] = distancias[j + 1];
        distancias[j + 1] = tempDist;

        // Troca de índices de cor correspondente
        int tempIndex = indices_cor[j];
        indices_cor[j] = indices_cor[j + 1];
        indices_cor[j + 1] = tempIndex;
      }
    }
  }

  // Se faz a votação com os 3 vizinhos mais próximos (K=3)
  int votos[6] = {0, 0, 0, 0, 0, 0};  // 6 posições, uma para cada cor

  for (int i = 0; i < 3; i++) {
    votos[indices_cor[i]]++;  // Adiciona um voto para a cor correspondente
  }

  // Encontra a cor com o maior número de votos
  int maiorVoto = 0;
  int indiceCor = -1;
  for (int i = 0; i < 6; i++) {
    if (votos[i] > maiorVoto) {
      maiorVoto = votos[i];
      indiceCor = i;
    }
  }
  // Exibe a cor identificada
  if (indiceCor != -1) {
    Serial.println(cores[indiceCor]); // Imprime na serial a cor identificada
    sequencia_cores += cores[indiceCor].charAt(0);  // Armazena a primeira letra da cor
  } else { // Se a cor for desconhecida, imprime mensagem na serial e adiciona 'X' na sequencia de cores lidas
    Serial.println("Desconhecida");
    sequencia_cores += 'X';
  }
}

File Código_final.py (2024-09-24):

# Autor: Lucas Arnaud de Araújo
# Trabalho de Conclusão de Curso em Engenharia Mecânica
# Universidade Federal de Pernambuco
# Projeto: ROBÔ SOLUCIONADOR DO CUBO DE RUBIK COM USO DE MOTORES DE PASSO E SENSORES DE COR
# Nome do arquivo: Código_final (utilizado no computador)
# Data de atualização: 17/09/2024

# Este código se divide em 3 partes:
# Parte 1: importação das bibliotecas, conexões com as seriais e definição das funções gerais;
# Parte 2: definição da função menu_principal que interege com o usuário e integra as funções gerais;
# Parte 3: execução da função menu_principal e fechamento das conexões seriais.

# Para mais detalhes acesse o arquivo PDF denominado [TCC_Lucas_Arnaud] disponibilizado nesta pasta do github.

#################################### PARTE 1 ####################################

############### IMPORTAÇÃO BIBLIOTECAS ################

# Importando bibliotecas
import serial
import time
import kociemba

############### CONEXÕES SERIAIS ################

# Configura a conexão serial para os sensores (Arduino UNO na porta serial COM 3)
try:  
    porta_serial_SENSORES = serial.Serial("COM3", 9600, timeout=1)  # Tenta abrir a porta serial COM3, com velocidade de 9600 bps e timeout de 1 segundo, para comunicação com o Arduino UNO e sensores
    print("Conectado à porta", porta_serial_SENSORES.portstr)  # Se a conexão acontecer, imprime uma mensagem confirmando a conexão e o nome da porta
except serial.SerialException:  # Caso ocorra um erro (porta não encontrada ou ocupada) na tentativa de conectar à porta serial 
    print("Porta USB não detectada")  # Imprime uma mensagem de erro informando que a porta não foi detectada
    exit()  # Encerra o programa após falha na conexão

# Configura a conexão serial para os motores (Arduino MEGA com a RAMPS 1.4 na porta serial COM 4)
try:
    porta_serial_MOTORES = serial.Serial("COM4", 250000)  # Tenta abrir a porta serial COM4, com velocidade de 250000 bps, usada para comunicação com os motores
    print("Conectado à porta", porta_serial_MOTORES.portstr)  # Se a conexão acontecer, imprime uma mensagem confirmando a conexão e o nome da porta
except serial.SerialException:  # Caso ocorra um erro (porta não encontrada ou ocupada) na tentativa de conectar à porta serial
    print("Porta USB não detectada")  # Imprime uma mensagem de erro informando que a porta não foi detectada
    exit()  # Encerra o programa após falha na conexão

############### DEFINIÇÕES DAS FUNÇÕES E DICIONÁRIO ################

#### DICIONÁRIO DOS COMANDOS G-CODE - FLUXOGRAMAS A, B e C
comandos = {
    "D":  ['G91','G0 X0.625 F300'],
    "D'": ['G91','G0 X-0.625 F300'],
    "D2": ['G91','G0 X1.250 F300'],
    "F":  ['G91','G0 Y-0.625 F300'],
    "F'": ['G91','G0 Y0.625 F300'],
    "F2": ['G91','G0 Y1.250 F300'],
    "R":  ['G91','G0 Z-0.625 F300'],
    "R'": ['G91','G0 Z0.625 F300'],
    "R2": ['G91','G0 Z1.250 F300'],
    "L":  ['M302 P1', 'T0', 'G91','G0 E0.625 F300'],
    "L'": ['M302 P1', 'T0', 'G91','G0 E-0.625 F300'],
    "L2": ['M302 P1', 'T0', 'G91','G0 E-1.250 F300'],
    "B":  ['M302 P1', 'T1', 'G91','G0 E0.625 F300'],
    "B'": ['M302 P1', 'T1', 'G91','G0 E-0.625 F300'],
    "B2": ['M302 P1', 'T1', 'G91','G0 E-1.250 F300'],
    "U":  ['M302 P1', 'T2', 'G91','G0 E2.500 F1500'],
    "U'": ['M302 P1', 'T2', 'G91','G0 E-2.500 F1500'],
    "U2": ['M302 P1', 'T2', 'G91','G0 E-5.000 F1500']
}

#### FUNÇÃO PARA ENVIAR COMANDOS PARA OS MOTORES - FLUXOGRAMAS A, B e C
def enviar_comando_motores(comando):
    porta_serial_MOTORES.write(bytes(comando + '\n', 'UTF-8'))  # Envia o comando, convertido em bytes com UTF-8, para a porta serial, adicionando uma nova linha no final
    time.sleep(0.250)  # Pequena pausa para garantir que o comando seja enviado

#### FUNÇÃO PARA MOVIMENTAR MOTORES A PARTIR DE UMA SEQUÊNCIA DE MOVIMENTOS - FLUXOGRAMAS A, B e C
def movimentar_motores(entrada):
    sequencia_movimentos = entrada.strip().upper() # Remove espaços em branco extras e transforma a sequência de movimentos em letras maiúsculas
    if sequencia_movimentos: # Verifica se a sequência de movimentos não está vazia
        movimentos = sequencia_movimentos.split() # Divide a sequência de movimentos em uma lista de comandos, assumindo que estão separados por espaços
        enviar_comando_motores('M302 P1') # Envia o comando 'M302 P1' para permitir a movimentação do extrusor a frio
        enviar_comando_motores('M203 E5') # Define a velocidade máxima do extrusor com o comando 'M203 E5'
        enviar_comando_motores('G91')     # Configura o sistema para modo de movimentação relativa, com o comando 'G91'
        
        for movimento in movimentos: # Para cada movimento na lista de movimentos
            if movimento in comandos: # Verifica se o movimento está na lista de comandos válidos
                gcode = comandos[movimento] # Obtém o comando G-code associado ao movimento a partir do dicionário 'comandos'
                
                # Para cada comando G-code associado ao movimento
                for cmd in gcode:
                    enviar_comando_motores(cmd) # Envia o comando G-code para os motores
            else: # Se o movimento não for reconhecido,
                print(f"Movimento '{movimento}' não reconhecido.")  # Imprime uma mensagem de erro
    else: # Se a sequência de movimentos estiver vazia
        print("Sequência de movimentos vazia.") # Imprime uma mensagem de aviso

#### FUNÇÃO ENVIAR COMANDOS PARA O ARDUINO UNO - FLUXOGRAMA C
def enviar_comando_sensores(comando):
    porta_serial_SENSORES.write(bytes(comando + '\n', 'UTF-8')) # Envia o comando, convertido em bytes com UTF-8, para a porta serial, adicionando uma nova linha no final
    time.sleep(0.1)  # Pequena pausa para garantir que o comando seja enviado

#### FUNÇÃO PARA LER LINHA DA SERIAL IMPRESSOS PELO ARDUINO UNO - FLUXOGRAMA C
def ler_linha_serial_sensores():
    return porta_serial_SENSORES.readline().decode('utf-8').strip()  # Lê uma linha completa da porta serial dos sensores, decodifica de UTF-8 para string, remove espaços em branco ou quebras de linha
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
